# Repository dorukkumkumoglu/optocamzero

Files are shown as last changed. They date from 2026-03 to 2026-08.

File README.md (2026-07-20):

# Optocam Zero

Optocam Zero is a Raspberry Pi Zero based compact digital camera made using off the shelf components. 

I designed Optocam Zero to have a very compact, carry everywhere and have fun sort of camera. As I was inspired by Kodak charmera and similar toy cameras, I wanted it to be feel playful, enjoyable and be intuitive to use. I also aimed to make it relatively easy to build so that others can also build one and have fun with it. That's why all the case parts are easily printable and for the electronics it uses off the shelf components that are easy to find.

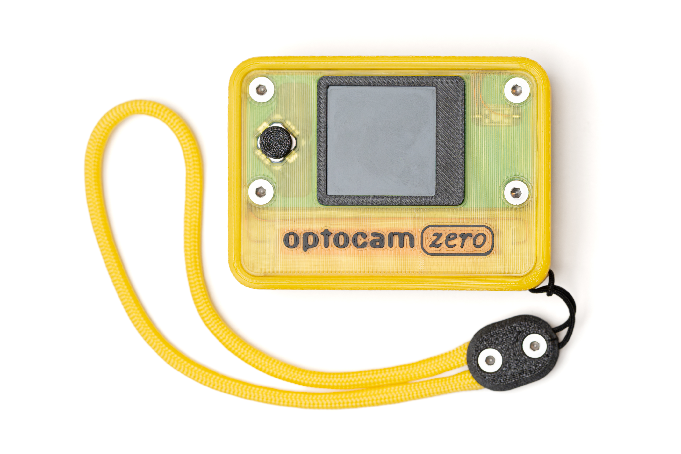
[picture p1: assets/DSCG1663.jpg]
exploded view


## Features
- **NEW** - GIF recording and playback.
- **NEW** - Custom filter maker (up to 5) in hotspot interface.
- Very compact and easy to carry in your pocket.
- Intuitive and simple camera interface and controls.
- Uses autofocus camera module.
- 8 photo filters included.
- Easy and fast image transfer through hotspot interface. Optimized both for mobile and desktop.
- Screen dimming when inactive to preserve battery.
- USB-C charging. Device can be used while charging.
- Interchangable battery.
- Off the shelf/ common components for the electronics.
- Fully 3D printed case parts (apart from fasteners).
- 3D printable TPU protective sleeve and lanyard design is available.

<br>

## Specs
- **UPDATE** - Now boots in 5 seconds with the buildroot image.
- **UPDATE** - Consistent 25-30 fps camera preview on the screen.
- 2592x2592px Jpeg image capture. Image saves in the background while preview stays active.
- 240x240px 1.4 inch lcd display.
- Uses 14500 type li-ion battery.
- 70–80 minutes of use per charge.
- Dimensions: 51×71×18mm (excluding camera and screen bump)
  
<br>

## Sample Photos

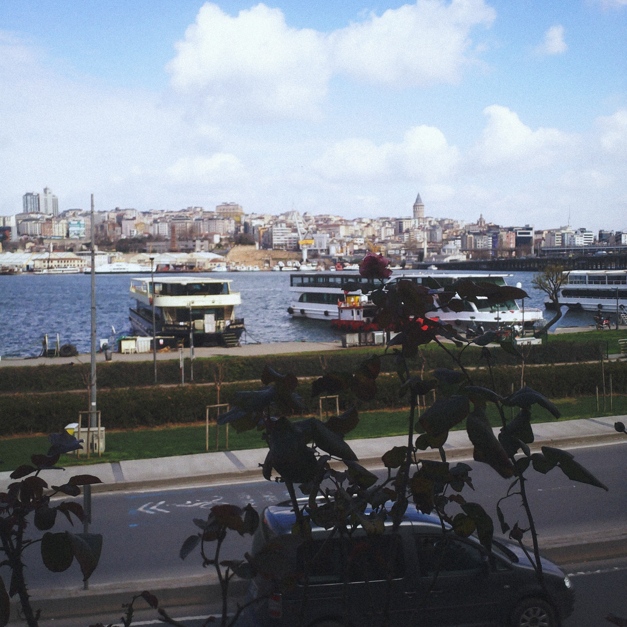
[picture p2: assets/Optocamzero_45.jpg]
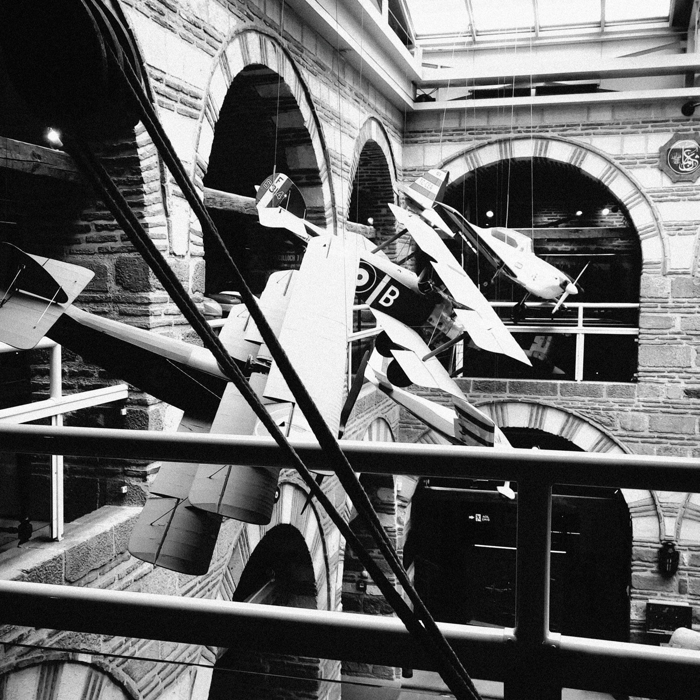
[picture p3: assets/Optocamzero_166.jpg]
 
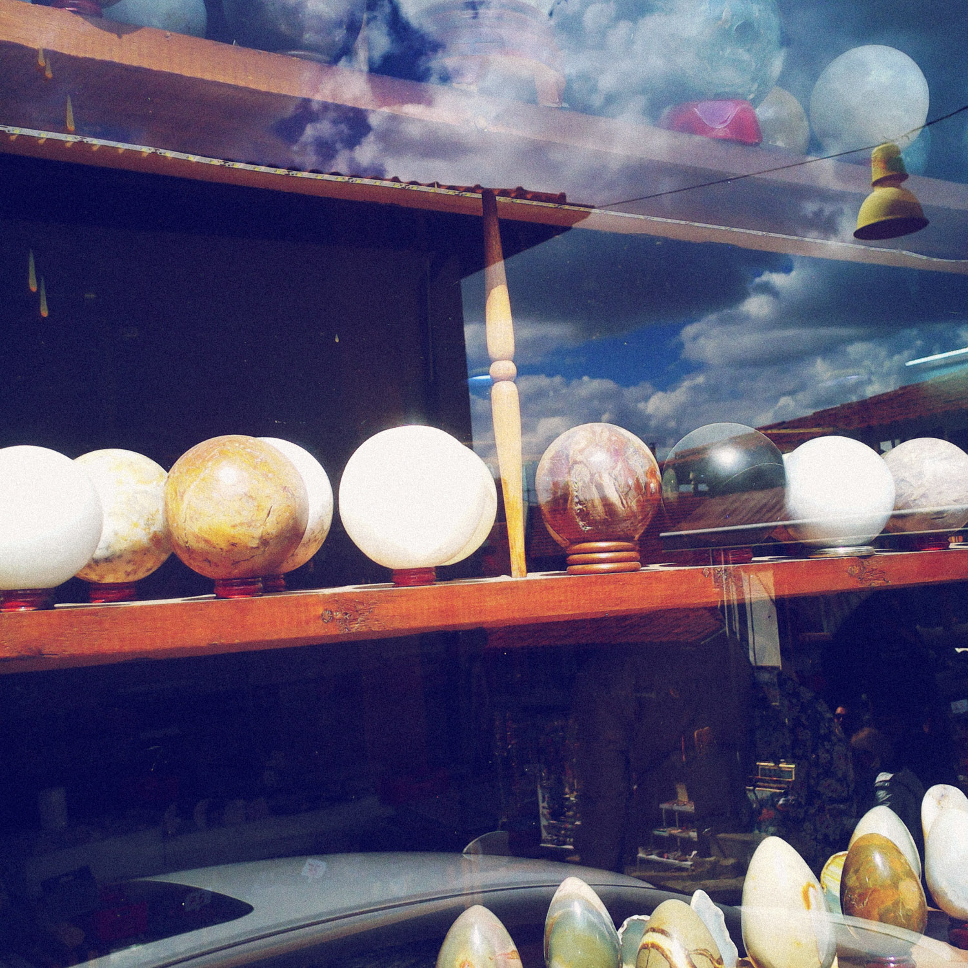
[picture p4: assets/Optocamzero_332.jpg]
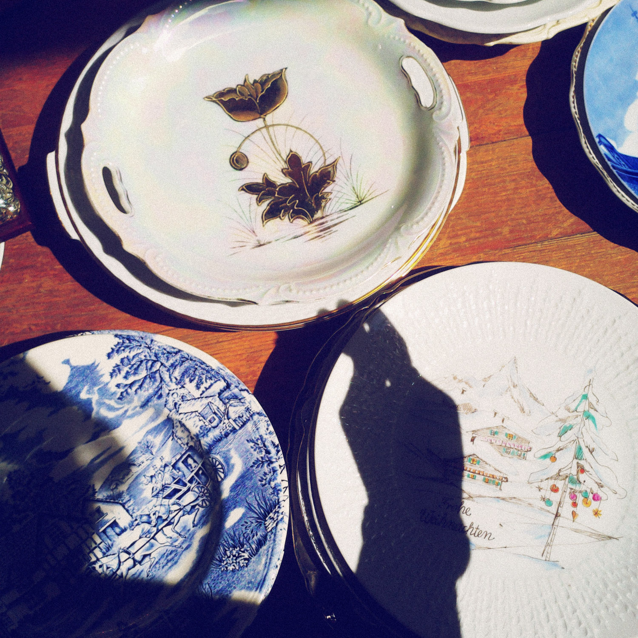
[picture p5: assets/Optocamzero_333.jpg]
 
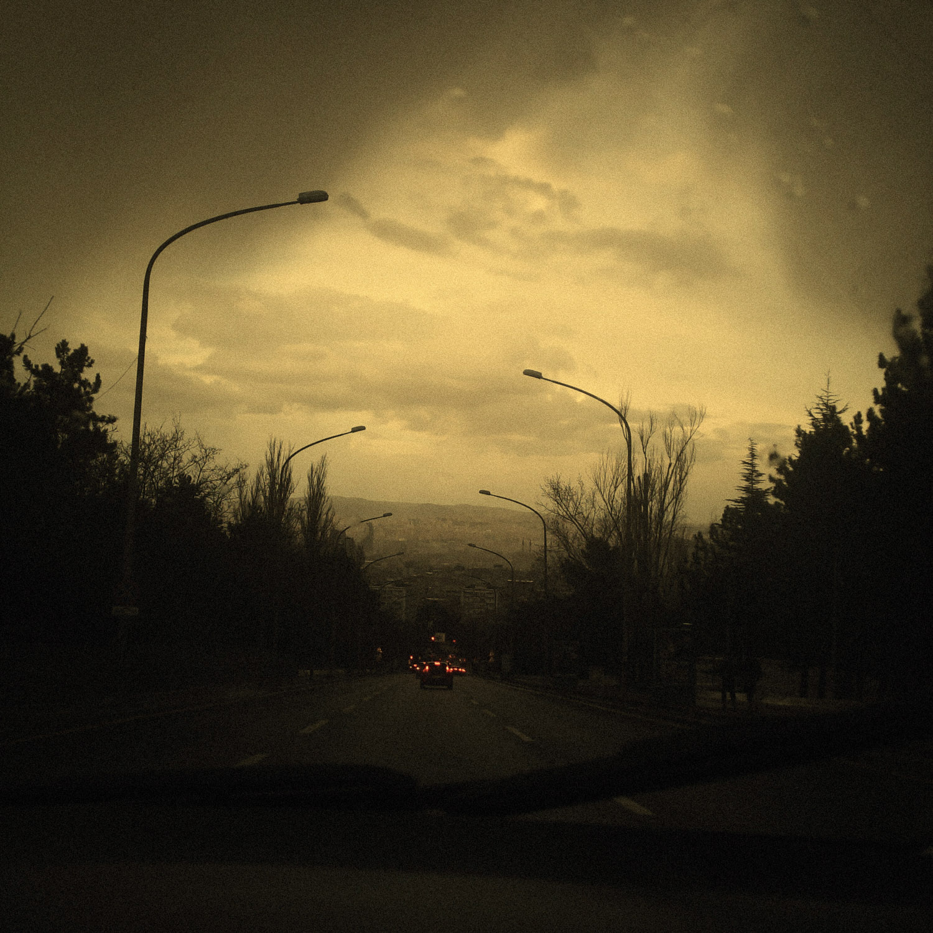
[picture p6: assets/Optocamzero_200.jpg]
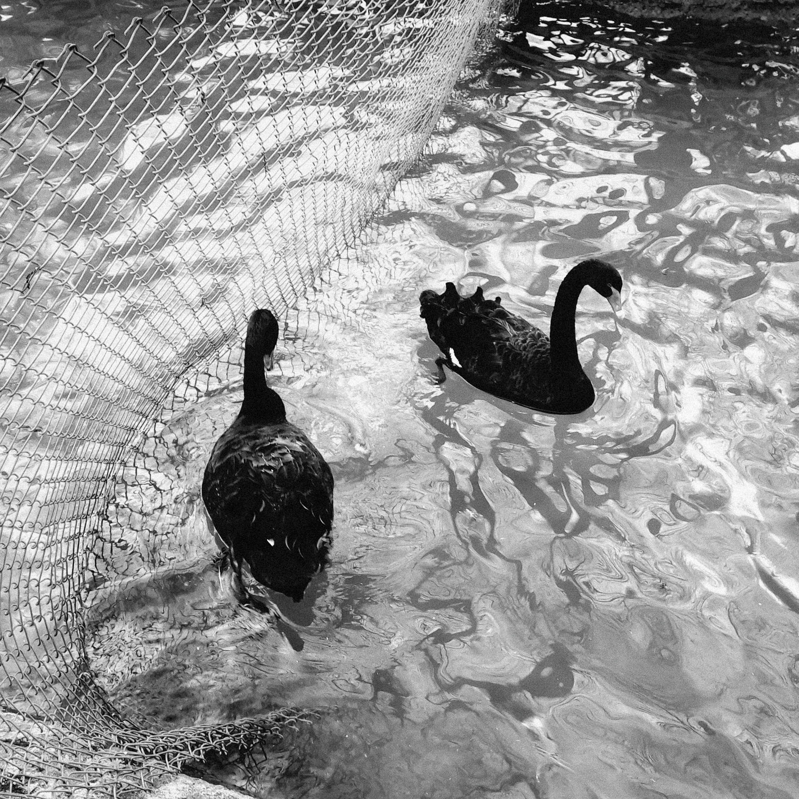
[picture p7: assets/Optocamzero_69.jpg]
 
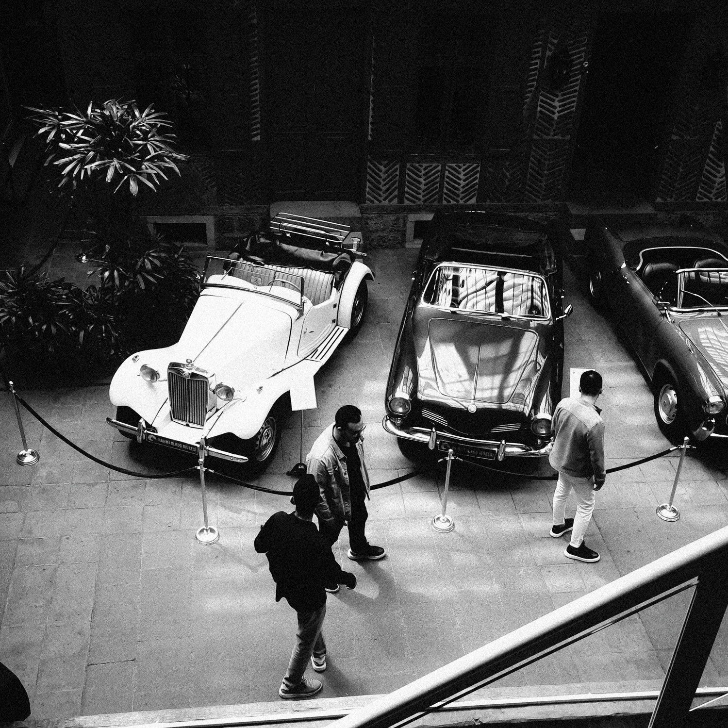
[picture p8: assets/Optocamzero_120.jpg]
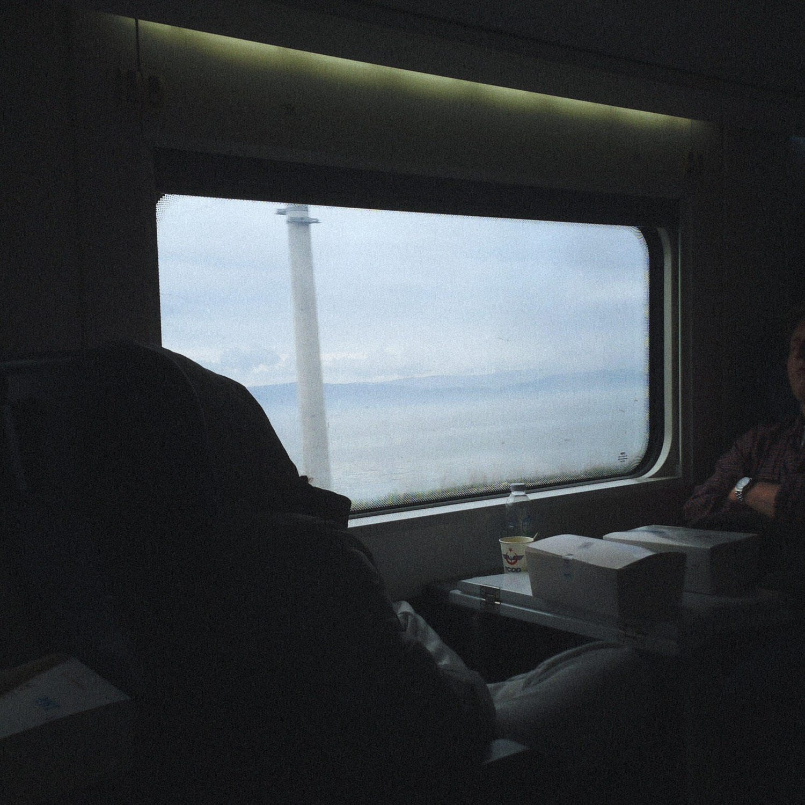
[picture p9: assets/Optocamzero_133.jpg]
 

<br>

## How to Build Optocam Zero?

Everything you need to build an Optocam Zero yourself is included in this repo.

All the 3d print files, Required parts list, and detailed step by step build guide can be found under the [hardware](hardware/) folder.

If you're considering building one, check the [BOM](hardware/BOM.md) to get an idea of the cost for required tools and parts.
Also, have a look at the [build guide](hardware/optocamzero-build-guide.pdf), it will give you a clear idea of what the build involves.

<br>

## Hardware

See the [hardware](hardware/) folder for:

- [Bill of materials](hardware/BOM.md).
- [Build guide](hardware/optocamzero-build-guide.pdf) (PDF).
- [Bambu Studio project files](hardware/print-ready/) ready to print for transparent PETG or PETG / PETG-CF.
- [Individual .stls](hardware/stls/) for camera parts.
- [CAD file](hardware/cad/optocamzero_V1.0.step) for customization.

<br>

## Software

See the [software](software/) folder for: 

- Optocam Zero code and installation guide.
- Camera controls information.

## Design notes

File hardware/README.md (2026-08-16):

# Optocam Zero Hardware

Everything you need to build an Optocam Zero, the 3D print files, required parts list, and detailed step by step build guide can be found in this hardware folder.

If you're considering building one, check the BOM to get an idea of the cost for required tools and parts. Also, have a look at the build guide, it will give you a clear idea of what the build involves.

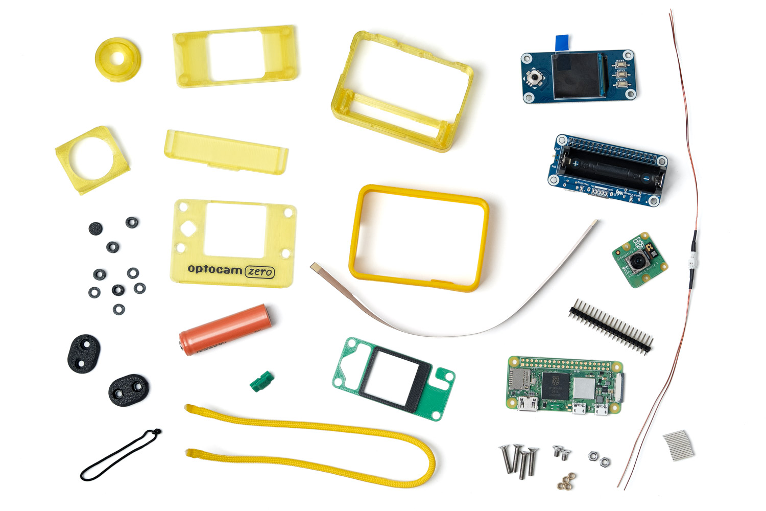
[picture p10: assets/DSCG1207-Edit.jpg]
exploded view


<br>

## 3D Printing the Parts

All parts are recommended to be printed with PETG for heat resistance. PLA parts may deform under heat generated by the electronics.

The parts are tested with PETG, transparent PETG and PETG-CF.

If you're using a Bambu Lab printer, ready to print Bambu Studio files are provided for Transparent PETG and PETG/PETG-CF. If you're printing transparent PETG, make sure the filament is well dried beforehand for maximum transparency.

All front and back pieces print flat on the plate, so whatever texture you have on your plate will be carried over to the front and back surfaces of your camera. For transparent PETG printing, I suggest using some kind of smooth plate if you want to achieve maximum transparency. Default textured plates will create a frosted look on transparent PETG, which has its own charm.

Two color 3D printing is only needed for the front cover logo and the two colored front spacer. If you don't want to have these, you can print all the pieces single color.

The optional case is printed with TPU. If you haven't printed with TPU before, check general TPU printing instructions.

**IMPORTANT:** The front spacer part that goes on top of the screen module has 2 versions with different thicknesses. This is because the LCD module on the display HAT may vary in thickness between batches. Test both front spacers and use the one that fits flush to the display HAT. Assembling the camera with the wrong front spacer part can damage the LCD.

<br>

## Before You Start

Make sure you have all the required parts, tools and 3D printed components ready before you begin.

Read through all the steps in the build guide before starting. Some steps have a specific order that can't be reversed easily.

This build requires basic soldering and desoldering. If you haven't soldered before, it's worth practicing on some scrap components first.

Take your time, especially with the ribbon cable (order extras to be safe) and the header pin soldering/desoldering. These are the most delicate parts of the build and mistakes here are difficult to undo. Be patient with it. 

<br>

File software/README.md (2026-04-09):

# Optocam Zero Software Installation and Interface Controls

<br>

## Requirements

- Completed Optocam Zero with the correct components.
- Micro sd card (16GB or larger, A2 type recommended for best performance).
- A computer with internet access.

<br>

## Installation

**1. Flash the SD card**

Download Raspberry Pi Imager from [raspberrypi.com/software](https://www.raspberrypi.com/software/) and install it. Select **Raspberry Pi Zero 2W** as the device and **Raspberry Pi OS Lite (32-bit) Bookworm** as the OS. You can find it under Raspberry Pi OS (other).

Before flashing, click **Edit Settings** and fill in your hostname, username, password, and WiFi credentials (remember to take note of this info). Go to the Services tab and enable SSH. Click Save, then flash the card.

**2. First boot**

Insert the SD card into the Pi and power it on. Wait about 1-2 minutes for it to boot and connect to your WiFi.

**3. Connect via SSH**

Open Terminal on your computer and run:

```
ssh your-username@your-hostname.local
```

Type `yes` when asked about the fingerprint, then enter your password.

**4. Run the installer**

```
sudo apt-get update
```

```
sudo apt-get install -y git
```

```
git clone https://github.com/dorukkumkumoglu/optocamzero.git && sudo bash optocamzero/software/install.sh
```

Installation takes about 10-15 minutes. The Pi reboots automatically when done and the camera starts immediately.

<br>

## Troubleshooting

**SSH shows "host key changed" error:**
```
ssh-keygen -R your-hostname.local
```

**Camera does not start after reboot:**
```
sudo systemctl status camera-auto.service
```

<br>

## Interface/ Controls

The device is turned on and off using the power switch on the right side. Reaching the camera preview after turning on the device takes 22 seconds.

Camera focus is set to continuous auto and cannot be adjusted manually. Camera shutter speed and ISO are set to auto and cannot be adjusted manually.

Currently, 8 different photo filters are included. You can switch between them. Color temperature can also be changed.

### Main camera preview screen controls
- Top left corner displays current color temperature (left-right joystick toggles between different color temperature modes).
- Top right corner displays current photo filter (up-down joystick toggles between different photo filters).
- Bottom left corner displays current ISO.
- Bottom right corner displays current shutter speed.
- A loading circle appears in the bottom center when an image is being saved. Wait for it to disappear before turning off the camera.

### Gallery controls
- Center joystick button opens the gallery.
- The numbers in the bottom left corner display the photo count and the currently displayed photo number.
- Left-right joystick navigates between photos in the gallery.
- Push joystick up for photo deletion. A confirmation overlay will appear. Push up once more to confirm deletion. Press any other button on the device to cancel.
- To exit the gallery, press the center joystick button or the shutter button. This will return to the main camera preview immediately.

### Transfer mode (Hotspot)
Optocam Zero includes a hotspot mode and photo transfer interface optimized for both mobile and desktop use.
- To activate transfer mode, long press the center joystick button.
- Long press the center joystick button again to exit transfer mode.
- To transfer images, connect your phone or computer to the Wi-Fi network called **Optocam Zero** (find the password on the screen) and open **192.168.4.1** in a browser.
- The dot in the top right corner and the number next to it indicate how many devices are currently connected to the hotspot. The dot turns green when a device is connected.

### Transfer interface (External Device)
After opening the address in a browser, the transfer interface will appear. All photos in your gallery are visible here and can be scrolled and browsed.

Below the header logo, the total image count and available free space are displayed.
- Photos can be downloaded individually by clicking the download icon in the top right corner of the photo.
- Multiple photos can be selected using the selectors in the top left corner of each image. After selection, you may batch download or delete the selected photos.
- For single image view, click on the image. Use the back button on screen to return, or swipe down on touch devices.
- In single image view, use the left-right arrow keys or swipe left-right to browse between photos.
- To view the full resolution image, click the HQ button in single image view.

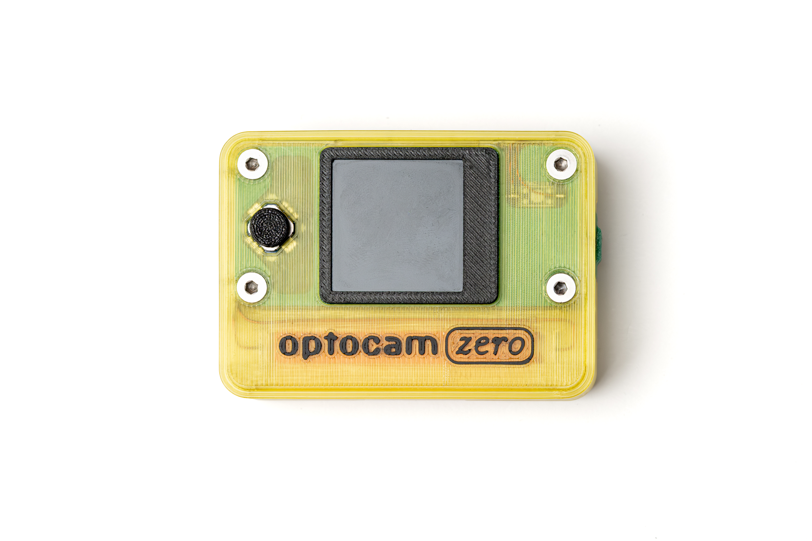
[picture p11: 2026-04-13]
assets/DSCG1642.jpg

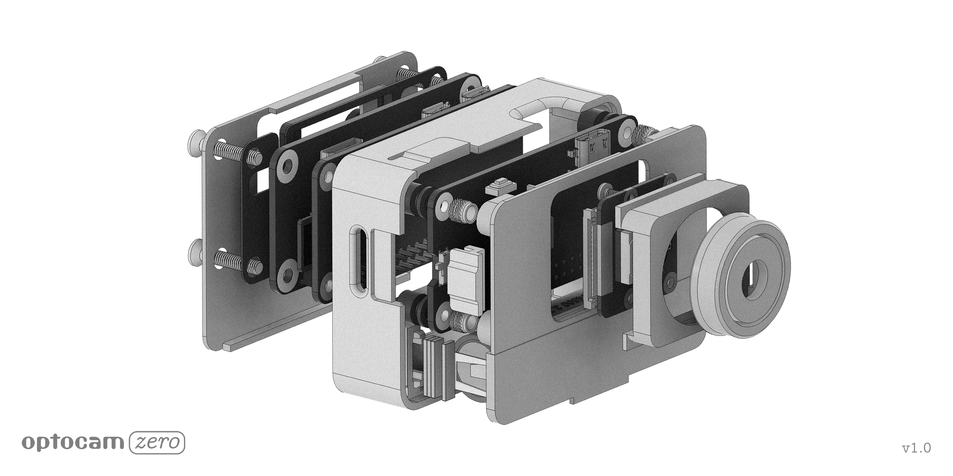
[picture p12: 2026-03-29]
assets/exploded-2.png

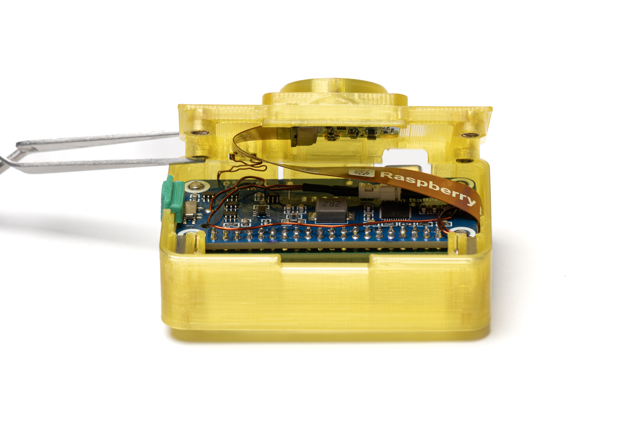
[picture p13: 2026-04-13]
assets/DSCG1636.jpg

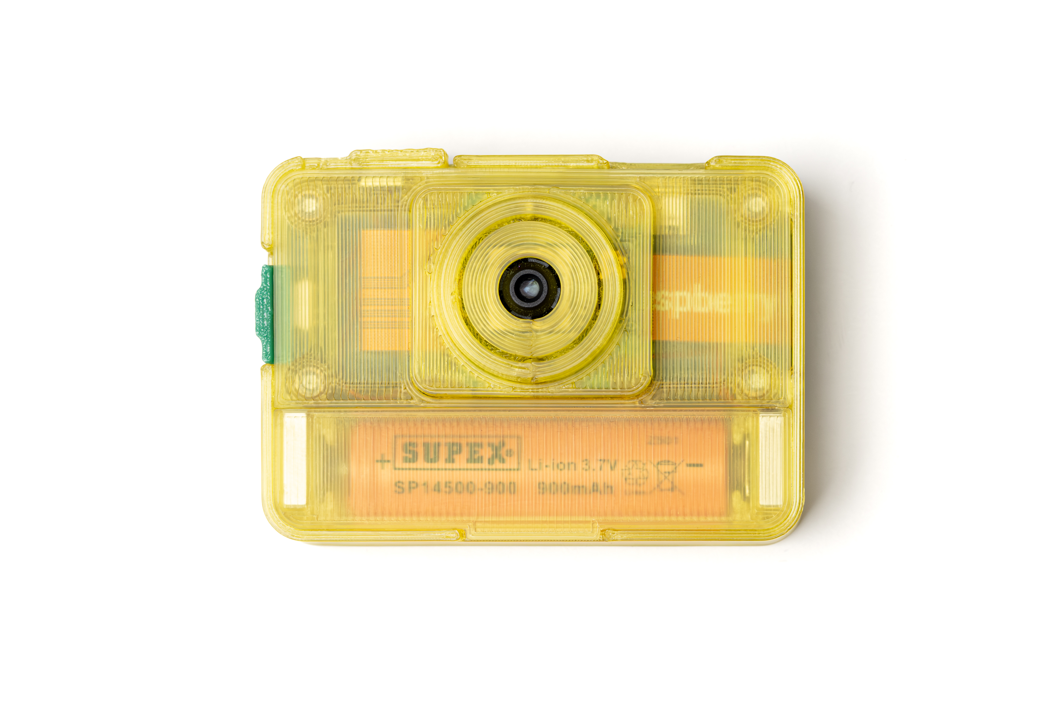
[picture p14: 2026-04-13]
assets/DSCG1643.jpg

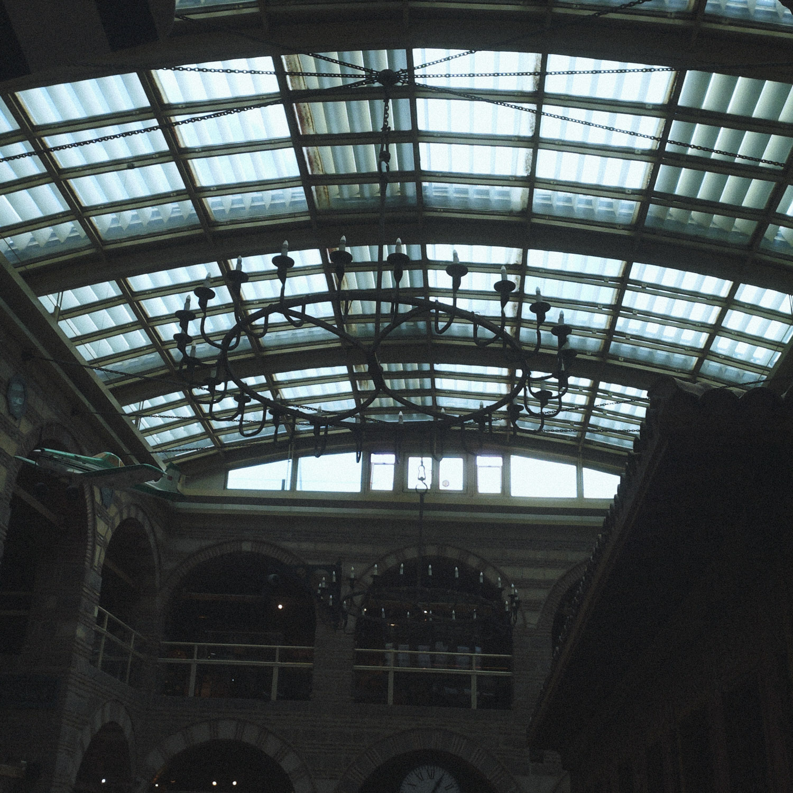
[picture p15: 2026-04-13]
assets/Optocamzero_97-2.jpg

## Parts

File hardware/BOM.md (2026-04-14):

# Optocam Zero V1.0 Bill of Materials
Doruk Kumkumoğlu 2026

<br>

## Electronics

| Item | Qty |
|---|-----|
| [Raspberry Pi Zero 2 W (without header)](https://thepihut.com/products/raspberry-pi-zero-2) | x1 |
| [Raspberry Pi Camera Module 3](https://thepihut.com/products/raspberry-pi-camera-module-3) | x1 |
| Micro SD Card A2 Class — Raspberry Pi or other high quality brands, minimum 16GB | x1 |
| [Waveshare Li-ion Battery HAT for Raspberry Pi](https://www.waveshare.com/li-ion-battery-hat.htm) | x1 |
| [Waveshare 1.3" IPS 240x240 LCD Display HAT for Raspberry Pi](https://www.waveshare.com/1.3inch-lcd-hat.htm) | x1 |
| [Camera Adapter Cable – Raspberry Pi Zero compatible (200mm)](https://thepihut.com/products/camera-adapter-cable-for-raspberry-pi-5) | x1 |
| 14500 Type 3.7V 900 mAh Li-ion Battery | x1 |
| Micro JST 1.25 Pitch 2 Pin Male and Female Connector Set (With 24 AWG Cable) — or 24 AWG cable (≥50cm length) | x1 |
| [2×20 Double Row Male GPIO Header](https://thepihut.com/products/break-away-0-1-2x20-pin-strip-dual-male-header) | x1 |
| 0.3mm Ø Enameled Copper Wire (≥30cm length) — or any thin signal cable | x1 |

<br>

## Fasteners

| Item | Qty |
|---|-----|
| M3×16mm Stainless Steel Hex-Drive Flat Head Screw | x4 |
| M2×6mm Screw (comes with the Waveshare Display HAT) | x2 | 
| [M3×4mm×4mm Brass Heat Set Insert](https://www.adafruit.com/product/4255) | x4 |
| 12×3×1mm Neodymium Magnet | x8 |

<br>

## Optional Fasteners

| Item | Qty |
|---|-----|
| M3×6mm Stainless Steel Hex-Drive Flat Head Screw (For Lanyard Lock) | x2 |
| M3 Stainless Steel Nut (For Lanyard Lock) | x2 |

<br>

## 3D Printed Parts and Materials

| Item | Material | Qty |
|---|---|-----|
| Enclosure | PETG | x1 |
| Back Panel | PETG | x1 |
| Camera Cover | PETG | x1 |
| Camera Circle | PETG | x1 |
| Front Spacer | PETG | x1 |
| Front Panel | PETG | x1 |
| Battery Door | PETG | x1 |
| Battery Level Visor | PETG | x1 |
| On/Off Button | PETG | x1 |
| Joystick Button | PETG | x1 |
| Washer 1mm | PETG | x4 |
| Washer 4mm | PETG | x4 |

<br>

## Optional 3D Printed Parts

| Item | Material | Qty |
|---|---|-----|
| Lanyard Lock Parts | PETG | x1 |
| Camera Sleeve | TPU | x1 |

<br>

## Optional – Cords & Straps

| Item | Qty |
|---|-----|
| Paracord – 1mm Ø, ≥30cm length | x1 |
| Paracord – 4mm Ø, ≥1m length | x1 |

<br>

## Tools

- 3D Printer
- Soldering Iron
- M3 Heat Set Insert Tip For Soldering Iron
- Solder Pump
- Solder
- Flux
- Kapton Tape
- 2mm (M3) Hex Driver
- Utility Knife
- Pliers
- Side Cutter
- Tweezers

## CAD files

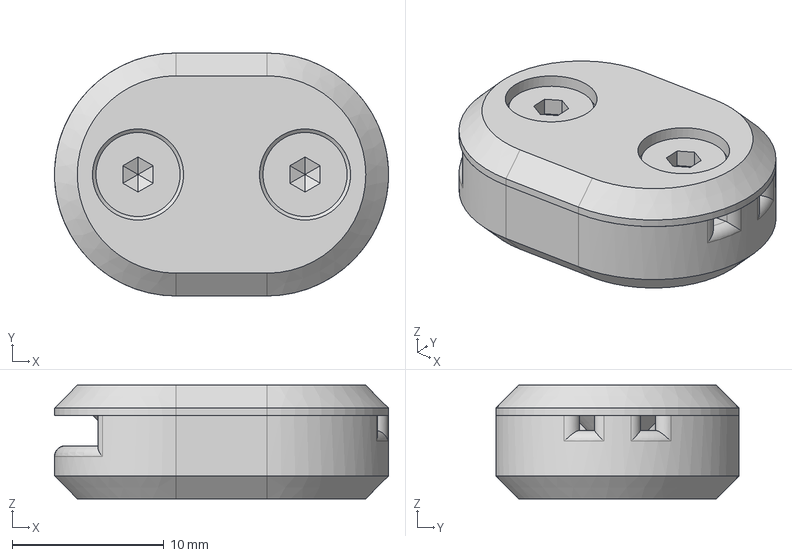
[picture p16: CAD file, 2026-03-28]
hardware/cad/lanyard-lock_V1.0.step
22.0 x 16.0 x 7.50 mm
ISO 10642 - M3 x 6 Steel 8.8 Plain
ISO 10642 - M3 x 6 Steel 8.8 Plain_1
ISO 4035 - M3 Steel 6 Plain
ISO 4035 - M3 Steel 6 Plain_1
Top
Bottom

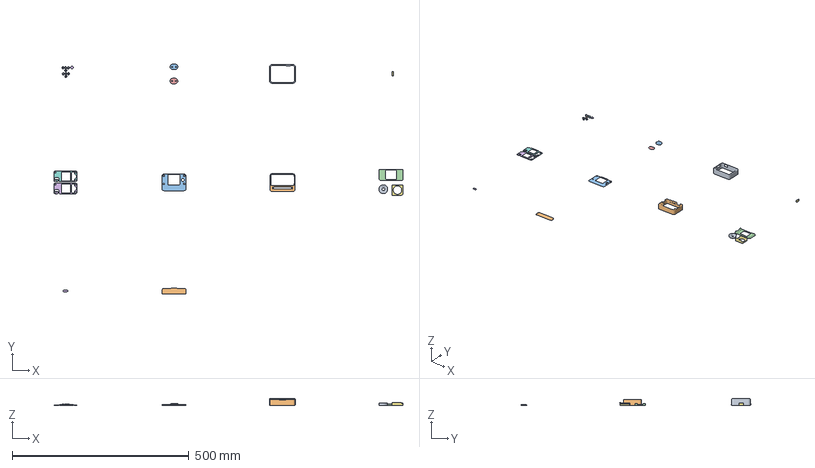
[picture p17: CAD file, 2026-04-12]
hardware/print-ready/optocamzero_v1.0_bambustudio.3mf
988.1 x 650.9 x 19.5 mm
Case
enclosure-opaque_v1.0.stl
top
Back Cover
bottom
front-spacer_v1.0.stl
Camera Cover
Front spacer B (For thicker screen)
Camera Circle
Battery Door
Front Panel
washer 4mm x 4
washer 1mm x 4
Joystick Button
On/ Off Button
Battery level visor

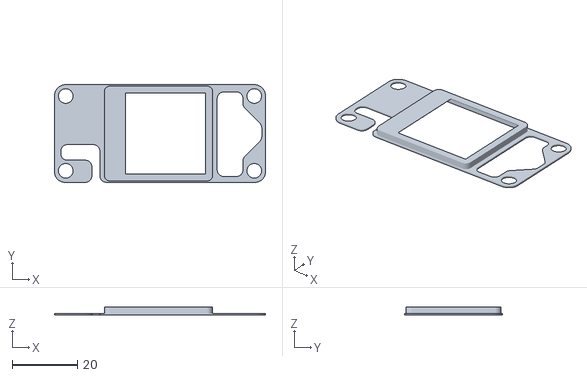
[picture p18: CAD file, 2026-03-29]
hardware/stls/front-spacer_v1.0.stl
64.9 x 30.0 x 2.40

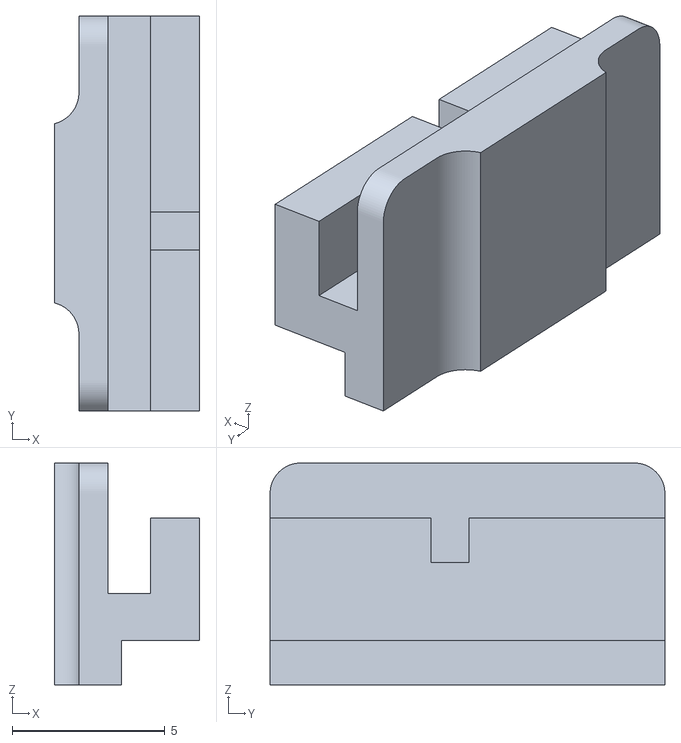
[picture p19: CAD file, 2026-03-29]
hardware/stls/on-off-button_v1.0.stl
4.75 x 12.9 x 7.27

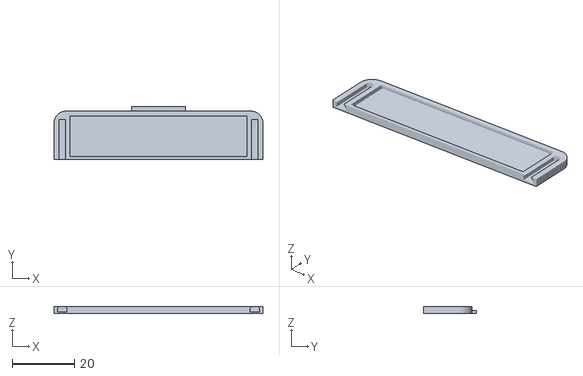
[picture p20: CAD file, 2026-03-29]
hardware/stls/battery-door_v1.0.stl
67.3 x 17.0 x 2.20

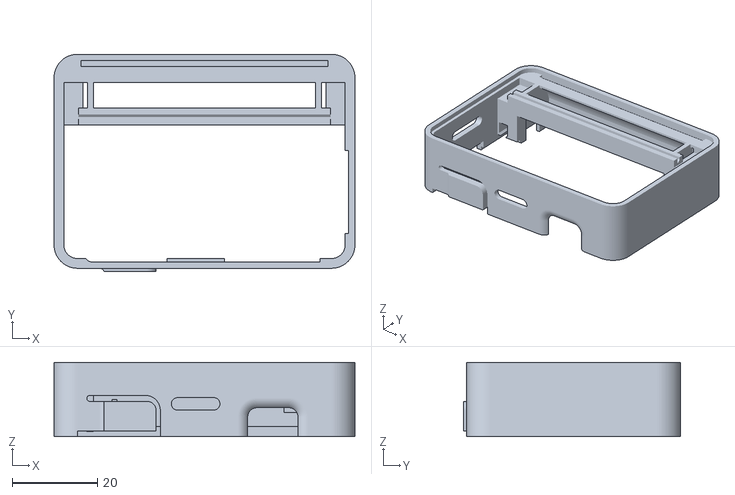
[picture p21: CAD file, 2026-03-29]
hardware/stls/enclosure-opaque_v1.0.stl
70.5 x 50.9 x 17.4

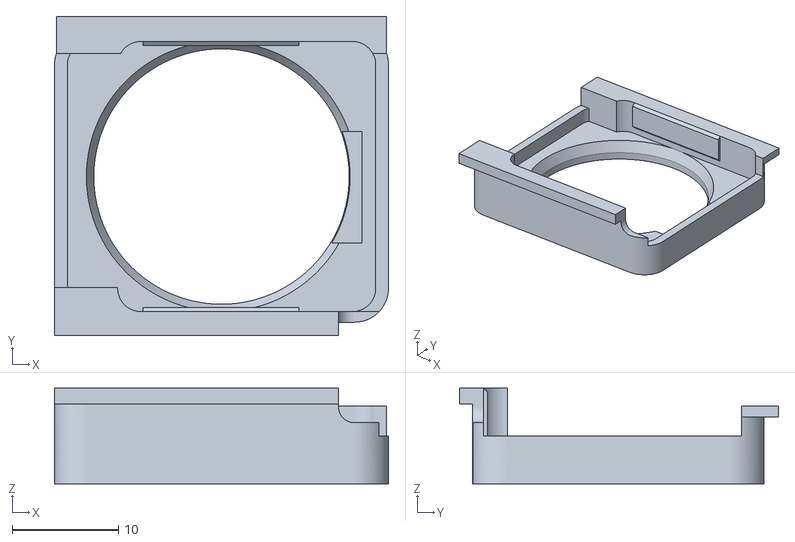
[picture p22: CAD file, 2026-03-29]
hardware/stls/camera-cover_v1.0.stl
31.4 x 30.0 x 9.00

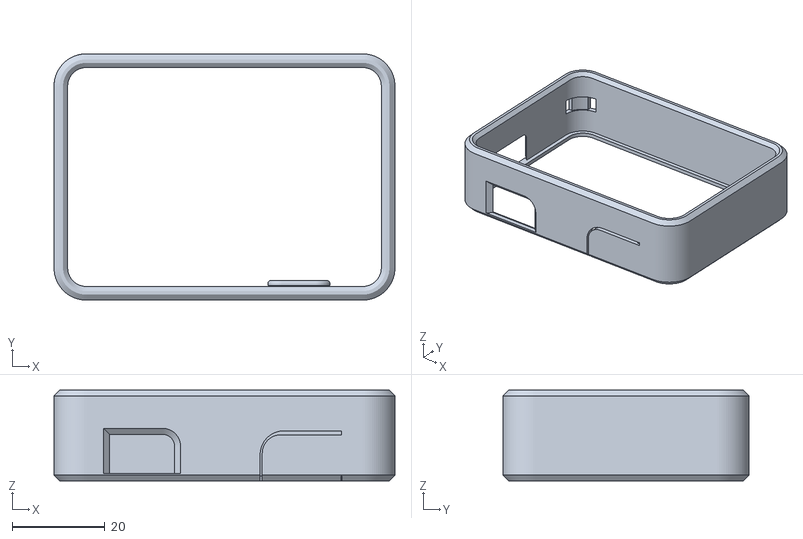
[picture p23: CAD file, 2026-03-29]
hardware/stls/case_v1.0.stl
73.4 x 53.0 x 19.5

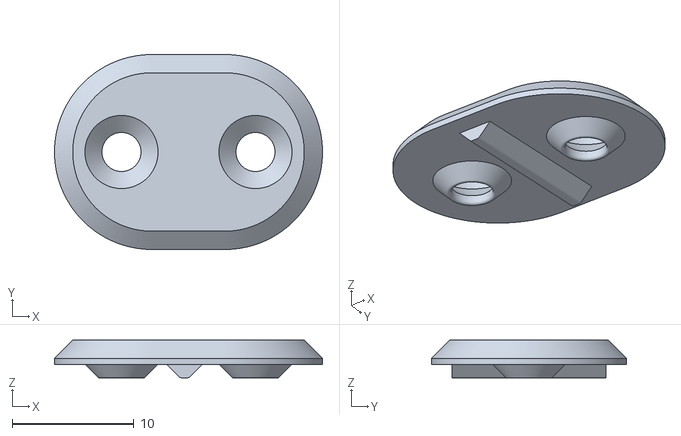
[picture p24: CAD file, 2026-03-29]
hardware/stls/lanyard-lock-top_v1.0.stl
22.0 x 16.0 x 3.12

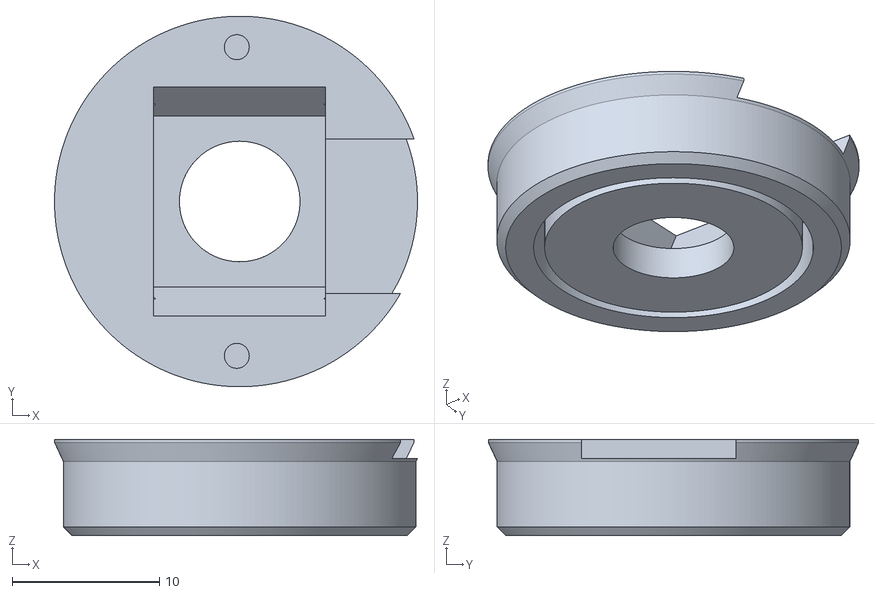
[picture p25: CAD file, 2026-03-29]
hardware/stls/camera-circle_v1.0.stl
24.7 x 25.2 x 6.55

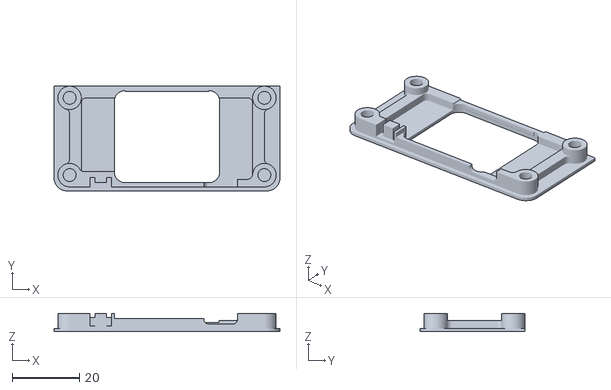
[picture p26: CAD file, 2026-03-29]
hardware/stls/back-panel_v1.0.stl
67.3 x 31.2 x 5.50

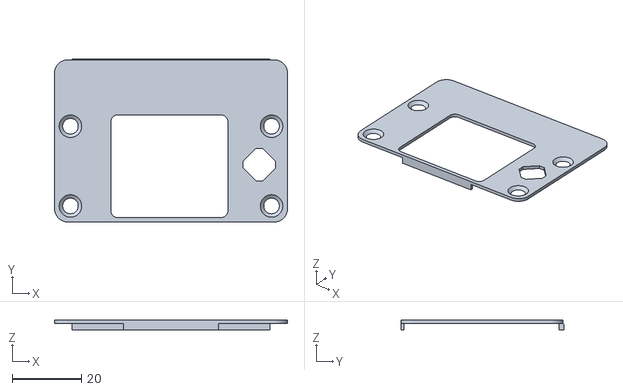
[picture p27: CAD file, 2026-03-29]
hardware/stls/front-panel_v1.0.stl
67.2 x 47.1 x 3.00

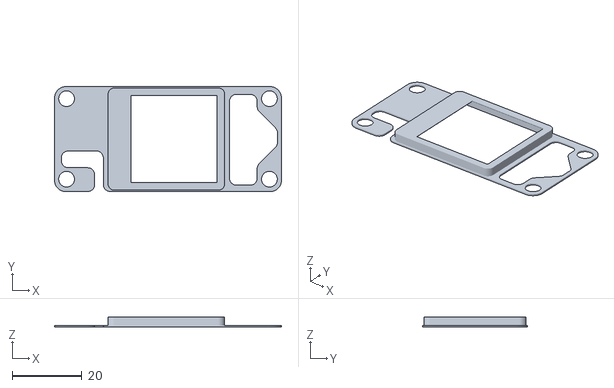
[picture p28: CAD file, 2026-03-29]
hardware/stls/front-spacer-thicker-screen_v1.0.stl
64.9 x 30.0 x 2.90

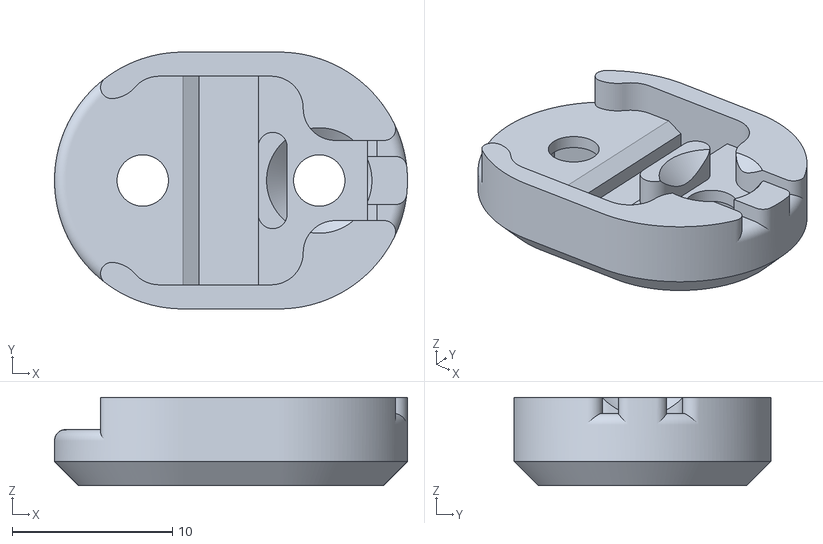
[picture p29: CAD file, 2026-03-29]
hardware/stls/lanyard-lock-bottom_v1.0.stl
22.0 x 16.0 x 5.50

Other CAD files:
hardware/print-ready/optocamzero-transparent_v1.0_bambustudio.3mf
hardware/stls/enclosure_v1.0.stl
hardware/stls/joystick-button_v1.0.stl
hardware/stls/battery-level-visor_v1.0.stl

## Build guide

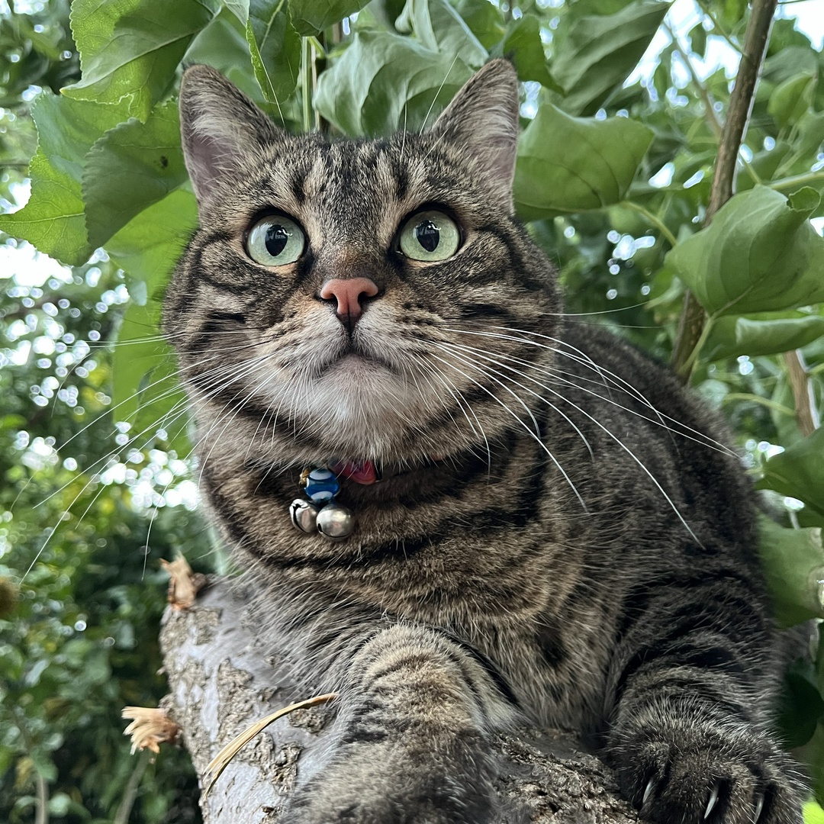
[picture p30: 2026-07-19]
software/firmware-buildroot/overlay/usr/share/optocam/calib_photo.jpg

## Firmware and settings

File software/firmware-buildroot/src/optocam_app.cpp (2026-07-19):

/* optocam_app.cpp — OptoCam Buildroot Stage-2 app, step 1.
 * Everything optocam_preview.cpp does (5s boot preview), plus:
 *   - buttons via gpiochip ioctls (capture GPIO21, preview GPIO20,
 *     joystick L5/R26/PRESS13/U6/D19 — all pull-up, active-low)
 *   - shutter: switch to 2592x2592 still, JPEG q92 (libjpeg-turbo),
 *     rotated 90° to match the display, saved to /data/photos/
 *     Optocamzero_N.jpg with fsync (power-cut costs at most this file)
 *   - white shutter-flash on the display for feedback
 * Boot-critical path is unchanged: display first, cache-warm, entity wait.
 */
#include <cstdio>
#include <cstdlib>
#include <cstdint>
#include <cstring>
#include <unistd.h>
#include <fcntl.h>
#include <dirent.h>
#include <sys/ioctl.h>
#include <sys/mman.h>
#include <sys/mount.h>
#include <sys/stat.h>
#include <map>
#include <vector>
#include <memory>
#include <atomic>
#include <mutex>
#include <chrono>
#include <condition_variable>
#include <thread>
#include <linux/spi/spidev.h>
#include <linux/gpio.h>
#include <linux/media.h>
#include <libcamera/libcamera.h>
#include <jpeglib.h>
#include <setjmp.h>
#include <csignal>
#include "optocam_hud.h"
#include "optocam_gif.h"

using namespace libcamera;

/* ---------- ST7789 display (validated in Stage-1) ---------- */
static bool g_madctl_legacy = false;        /* A/B: original 0x70 panel mode */
static int spifd, rst_fd, dc_fd, bl_fd;
static int gpio_out(int chipfd, unsigned off, int val) {
    struct gpiohandle_request r; memset(&r, 0, sizeof r);
    r.lineoffsets[0] = off; r.lines = 1; r.flags = GPIOHANDLE_REQUEST_OUTPUT;
    r.default_values[0] = val; strcpy(r.consumer_label, "optocam");
    if (ioctl(chipfd, GPIO_GET_LINEHANDLE_IOCTL, &r) < 0) { perror("linehandle"); return -1; }
    return r.fd;
}
static void gpio_set(int fd, int v) { struct gpiohandle_data d; d.values[0] = v; ioctl(fd, GPIOHANDLE_SET_LINE_VALUES_IOCTL, &d); }
/* Memory-mapped fast path for the backlight pin (BCM 24): at the dim duty the
 * PWM pulse is 63µs, and the gpiochip ioctl's kernel-crossing latency under
 * IRQ load lands on the pulse edges as faint brightness wander. A register
 * store makes the edges nanosecond-exact regardless of load. The line stays
 * requested as output via gpiochip; both paths reach the same pad. */
static volatile uint32_t *g_gpioreg = nullptr;
static void bl_fast_init(void) {
    int fd = open("/dev/gpiomem", O_RDWR | O_SYNC);
    if (fd < 0) return;                     /* no gpiomem: ioctl fallback */
    void *m = mmap(nullptr, 4096, PROT_READ | PROT_WRITE, MAP_SHARED, fd, 0);
    close(fd);
    if (m != MAP_FAILED) g_gpioreg = (volatile uint32_t *)m;
}
static inline void bl_set(int v) {
    if (g_gpioreg) g_gpioreg[v ? 7 : 10] = 1u << 24;   /* GPSET0 / GPCLR0 */
    else gpio_set(bl_fd, v);
}
static void spi_write(const uint8_t *b, size_t len) {
    size_t off = 0;
    while (off < len) { size_t n = len - off; if (n > 65536) n = 65536;
        ssize_t w = write(spifd, b + off, n); if (w <= 0) { perror("spi"); return; } off += (size_t)w; }
}
static void dcmd(uint8_t c) { gpio_set(dc_fd, 0); spi_write(&c, 1); }
static void ddata(const uint8_t *d, size_t n) { gpio_set(dc_fd, 1); spi_write(d, n); }

static void display_init(bool soft) {
    /* soft: the early-splash binary already initialised the panel and is
     * holding the GPIO lines — kill it, re-grab the lines WITHOUT resetting
     * the panel (its RAM keeps showing the splash), and just take over. */
    if (soft) { system("killall optocam_splash 2>/dev/null"); usleep(50000); }
    /* at boot we race spi-bcm2835's async probe — retry until the nodes exist
     * (the "backlight on, nothing else" boot failure) */
    int chip = -1;
    for (int t = 0; t < 500 && (chip = open("/dev/gpiochip0", O_RDONLY)) < 0; t++) usleep(20000);
    rst_fd = gpio_out(chip, 27, 1); dc_fd = gpio_out(chip, 25, 0);
    bl_fd = gpio_out(chip, 24, soft ? 1 : 0);          /* keep backlight lit on takeover */
    close(chip);
    spifd = -1;
    for (int t = 0; t < 500 && (spifd = open("/dev/spidev0.0", O_RDWR)) < 0; t++) usleep(20000);
    if (spifd < 0) printf("optocam: SPIDEV OPEN FAILED\n");
    uint8_t mode = SPI_MODE_0, bits = 8; uint32_t sp = 100000000;
    ioctl(spifd, SPI_IOC_WR_MODE, &mode); ioctl(spifd, SPI_IOC_WR_BITS_PER_WORD, &bits);
    ioctl(spifd, SPI_IOC_WR_MAX_SPEED_HZ, &sp);
    uint8_t mode2 = SPI_MODE_0, bits2 = 8; uint32_t sp2 = 100000000;
    ioctl(spifd, SPI_IOC_WR_MODE, &mode2); ioctl(spifd, SPI_IOC_WR_BITS_PER_WORD, &bits2);
    ioctl(spifd, SPI_IOC_WR_MAX_SPEED_HZ, &sp2);
    if (soft) return;                                  /* panel already showing splash */
    gpio_set(rst_fd, 1); usleep(50000); gpio_set(rst_fd, 0); usleep(50000); gpio_set(rst_fd, 1); usleep(80000);
    struct { uint8_t c, n, d[16]; } in[] = {
        {(uint8_t)0x36,(uint8_t)1,{g_madctl_legacy ? (uint8_t)0x70 : (uint8_t)0x00}},{0x3A,1,{0x05}},{0xB2,5,{0x0C,0x0C,0x00,0x33,0x33}},{0xB7,1,{0x35}},{0xBB,1,{0x35}},
        {0xC0,1,{0x2C}},{0xC2,1,{0x01}},{0xC3,1,{0x13}},{0xC4,1,{0x20}},{0xC6,1,{0x0F}},{0xD0,2,{0xA4,0xA1}},
        {0xE0,14,{0xF0,0x00,0x04,0x04,0x04,0x05,0x29,0x33,0x3E,0x38,0x12,0x12,0x28,0x30}},
        {0xE1,14,{0xF0,0x07,0x0A,0x0D,0x0B,0x07,0x28,0x33,0x3E,0x36,0x14,0x14,0x29,0x32}},
        {0x21,0,{0}},{0x11,0,{0}},
    };
    for (unsigned i = 0; i < sizeof(in)/sizeof(in[0]); i++) { dcmd(in[i].c); if (in[i].n) ddata(in[i].d, in[i].n); if (in[i].c == 0x11) usleep(80000); }
    dcmd(0x29);   /* backlight stays OFF until the splash is drawn (like the app) */
}
static uint8_t fb565[240*240*2];
static unsigned FW, FH, FSTRIDE;
/* fused contrast + RGB565 LUTs, exactly the Python app's display path:
 * (x - 128) * 1.15 + 123, then masked/shifted per channel */
static uint16_t R565[256], G565[256], B565[256];
/* optional saturation stage: 4th dispcal float ≠ 1.0 activates a 3x3 colour
 * matrix (white-point gains folded in) baked into 9 int16 LUTs — per pixel:
 * 9 loads + 6 adds + clamps. sat==1.0 keeps the original 3-LUT path. */
static int16_t M9[3][3][256];
static bool g_sat_on = false;
static inline uint16_t px565(uint8_t r, uint8_t g, uint8_t b) {
    if (!g_sat_on) return R565[r] | G565[g] | B565[b];
    int rv = M9[0][0][r] + M9[0][1][g] + M9[0][2][b];
    int gv = M9[1][0][r] + M9[1][1][g] + M9[1][2][b];
    int bv = M9[2][0][r] + M9[2][1][g] + M9[2][2][b];
    rv = rv < 0 ? 0 : rv > 255 ? 255 : rv;
    gv = gv < 0 ? 0 : gv > 255 ? 255 : gv;
    bv = bv < 0 ? 0 : bv > 255 ? 255 : bv;
    return (uint16_t)((rv & 0xF8) << 8) | (uint16_t)((gv & 0xFC) << 3) | (uint16_t)((bv & 0xF8) >> 3);
}
/* camera WB shift — the amber/blue fine-tune real cameras offer: a fixed RGB
 * trim applied to CAMERA pixels only (live preview, photos, gifs), never the
 * UI. Predictable and AWB-independent, unlike tuning-file knobs where the WB
 * gains and the CT-dependent colour matrix partially cancel each other.
 * /data/.wbtrim (or baked /usr/share/optocam/wbtrim): "R G B" floats. */
static uint8_t WBL[3][256];
static bool g_wb_on = false;
static void build_wb_trim(void) {
    float tr = 1, tg = 1, tb = 1;
    FILE *f = fopen("/data/.wbtrim", "r");
    if (!f) f = fopen("/usr/share/optocam/wbtrim", "r");
    if (f) {
        float r, g, b;
        if (fscanf(f, "%f %f %f", &r, &g, &b) == 3 &&
            r > 0.5f && r <= 1.5f && g > 0.5f && g <= 1.5f && b > 0.5f && b <= 1.5f) {
            tr = r; tg = g; tb = b;
        }
        fclose(f);
    }
    for (int i = 0; i < 256; i++) {
        auto q = [](float v) { return (uint8_t)(v < 0 ? 0 : v > 255 ? 255 : v); };
        WBL[0][i] = q(i * tr); WBL[1][i] = q(i * tg); WBL[2][i] = q(i * tb);
    }
    g_wb_on = tr != 1.0f || tg != 1.0f || tb != 1.0f;
}
static void wb_apply(uint8_t *p, size_t npx, bool bgr) {
    if (!g_wb_on) return;
    int ri = bgr ? 2 : 0, bi = bgr ? 0 : 2;
    for (size_t i = 0; i < npx; i++, p += 3) {
        p[ri] = WBL[0][p[ri]]; p[1] = WBL[1][p[1]]; p[bi] = WBL[2][p[bi]];
    }
}
/* device baseline contrast: photos map i -> (i-128)*1.15 + 123. The calibration
 * "contrast" slider scales that 1.15 (default keeps the shipped look). */
static constexpr float BASE_CONTRAST = 1.15f;
/* Calibration transfer applied per display pixel, baked into the LUTs so it
 * costs nothing per frame. Order: contrast -> gamma -> per-channel gain (+ an
 * optional saturation matrix). Returns a normalised 0..1 tone; the per-channel
 * gain is applied by the caller. */
static inline float calib_tone(int i, float contrast, float inv_gamma) {
    float c = (i - 128) * contrast + 123.0f;
    c = c < 0 ? 0 : c > 255 ? 255 : c;
    float n = c / 255.0f;
    if (inv_gamma < 0.999f || inv_gamma > 1.001f) n = powf(n, inv_gamma);
    return n;
}
/* core LUT builder: per-channel white-point gains, saturation, gamma and
 * contrast. Split out so the transfer-mode screen calibrator can rebuild the
 * LUTs live from slider values (see /data/.calib) without re-reading a file. */
static void build_565_luts_from(float gr, float gg, float gb, float sat,
                                float gamma, float contrast) {
    float inv_g = (gamma > 0.05f) ? 1.0f / gamma : 1.0f;
    auto q = [](float v) -> uint16_t { return v < 0 ? 0 : v > 255 ? 255 : (uint16_t)v; };
    for (int i = 0; i < 256; i++) {
        float n = calib_tone(i, contrast, inv_g);
        R565[i] = (q(255.0f * n * gr) & 0xF8) << 8;
        G565[i] = (q(255.0f * n * gg) & 0xFC) << 3;
        B565[i] = (q(255.0f * n * gb) & 0xF8) >> 3;
    }
    if (sat < 0.99f || sat > 1.01f) {
        /* standard luma-preserving saturation matrix, white gains folded in */
        const float W[3] = {gr, gg, gb}, LR = 0.299f, LG = 0.587f, LB = 0.114f;
        const float S[3][3] = {
            {LR + (1-LR)*sat, LG*(1-sat),      LB*(1-sat)},
            {LR*(1-sat),      LG + (1-LG)*sat, LB*(1-sat)},
            {LR*(1-sat),      LG*(1-sat),      LB + (1-LB)*sat}};
        for (int i = 0; i < 3; i++)
            for (int j = 0; j < 3; j++)
                for (int v = 0; v < 256; v++) {
                    float base = 255.0f * calib_tone(v, contrast, inv_g);
                    M9[i][j][v] = (int16_t)lrintf(W[i] * S[i][j] * base);
                }
        g_sat_on = true;
    } else g_sat_on = false;
}
/* Calibrated backlight duty, 51..255 (255 = solid DC, no PWM). The "screen
 * brightness" calibration slider lands here — real luminance via the BL pin,
 * never a pixel gain, so it can't clip highlights or cost tonal bits. */
static std::atomic<int> g_bl_level(255);
/* panel white-point calibration: this unit's LCD batch runs bluer than the
 * original device's (identical init registers + identical conversion were
 * verified — the difference is the glass). /data/.dispcal holds up to seven
 * floats "GR GG GB [SAT GAMMA CONTRAST BACKLIGHT]" (written by the hotspot
 * Screen-Calibration panel on save); absent fields fall back to neutral / the
 * baked contrast / full backlight. The baked fallback file stays 3-float and
 * back-compatible. Gain bounds are INCLUSIVE of 0.2 — the server clamps to
 * exactly 0.2, and `>` here used to reject such a profile wholesale. */
static bool read_dispcal(const char *path, float &gr, float &gg, float &gb,
                         float &sat, float &gamma, float &contrast, float &bl) {
    FILE *cal = fopen(path, "r");
    if (!cal) return false;
    float r, g, b, s = 1.0f, ga = 1.0f, ct = BASE_CONTRAST, lv = 1.0f;
    int n = fscanf(cal, "%f %f %f %f %f %f %f", &r, &g, &b, &s, &ga, &ct, &lv);
    fclose(cal);
    if (n >= 3 && r >= 0.2f && r <= 2.5f && g >= 0.2f && g <= 2.5f && b >= 0.2f && b <= 2.5f) {
        gr = r; gg = g; gb = b;
        sat      = (n >= 4 && s  >= 0.0f && s  <= 2.5f) ? s  : 1.0f;
        gamma    = (n >= 5 && ga >= 0.3f && ga <= 3.0f) ? ga : 1.0f;
        contrast = (n >= 6 && ct >= 0.2f && ct <= 2.5f) ? ct : BASE_CONTRAST;
        bl       = (n >= 7 && lv >= 0.2f && lv <= 1.0f) ? lv : 1.0f;
        return true;
    }
    return false;
}
static void build_565_luts(void) {
    float gr = 1.0f, gg = 1.0f, gb = 1.0f, sat = 1.0f, gamma = 1.0f, contrast = BASE_CONTRAST, bl = 1.0f;
    if (!read_dispcal("/data/.dispcal", gr, gg, gb, sat, gamma, contrast, bl))   /* /data mounts late — */
        read_dispcal("/usr/share/optocam/dispcal", gr, gg, gb, sat, gamma, contrast, bl);  /* baked fallback */
    build_565_luts_from(gr, gg, gb, sat, gamma, contrast);
    g_bl_level.store((int)lrintf(bl * 255.0f));
}
/* Writes now happen in the panel's PHYSICAL scan order (MADCTL 0x00) and the
 * old hardware remap (0x70: MV|MX) is applied in software — same image, but
 * the write pointer moves WITH the scan instead of across it, which turns the
 * harsh diagonal tearing into occasional mild banding (esp-idf #15265 clue).
 * Variant selectable via /tmp/rot (0-7) for on-device axis calibration. */
static int fb_variant(void) { return g_madctl_legacy ? 1 : 2; }
static inline void fb_map(int variant, int i, int j, int &x, int &y) {
    switch (variant & 7) {
    case 0: x = 239 - i; y = j; break;        /* P70 guess: MV + MX */
    case 1: x = i;       y = j; break;
    case 2: x = i;       y = 239 - j; break;
    case 3: x = 239 - i; y = 239 - j; break;
    case 4: x = j;       y = i; break;
    case 5: x = 239 - j; y = i; break;
    case 6: x = j;       y = 239 - i; break;
    default: x = 239 - j; y = 239 - i; break;
    }
}
static void fb_store_565(const uint8_t *vis565) {       /* splash path (RGB565 in) */
    int v = fb_variant();
    for (int i = 0; i < 240; i++)
        for (int j = 0; j < 240; j++) {
            int x, y; fb_map(v, i, j, x, y);
            fb565[(i*240 + j)*2]     = vis565[(y*240 + x)*2];
            fb565[(i*240 + j)*2 + 1] = vis565[(y*240 + x)*2 + 1];
        }
}
static void fb_flush(void) {
    uint8_t win[4] = {0x00,0x00,0x00,0xEF};
    dcmd(0x2A); ddata(win, 4); dcmd(0x2B); ddata(win, 4); dcmd(0x2C); ddata(fb565, sizeof fb565);
}
static void display_blit(const uint8_t *rgb) {
    unsigned ox = FW > 240 ? (FW - 240) / 2 : 0, oy = FH > 240 ? (FH - 240) / 2 : 0;
    int v = fb_variant();
    for (int i = 0; i < 240; i++) {
        uint8_t *out = fb565 + i * 240 * 2;
        for (int j = 0; j < 240; j++) {
            int x, y; fb_map(v, i, j, x, y);
            int sx = 239 - y, sy = x;                 /* 90° to match panel mount */
            const uint8_t *px = rgb + (size_t)(oy + sy) * FSTRIDE + (size_t)(ox + sx) * 3;
            uint16_t c = px565(px[2], px[1], px[0]);
            out[j*2] = c >> 8; out[j*2+1] = c & 0xFF;
        }
    }
    fb_flush();
}
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
int main() {
    install_crash_handlers();
    logstep("main enter");
    g_madctl_legacy = access("/tmp/madctl-legacy", F_OK) == 0;
    build_565_luts();
    build_wb_trim();
    filters_init();
    if (!g_te.init("/usr/share/optocam/cmunvt.ttf")) printf("optocam: FONT INIT FAILED\n");
    logstep("luts+font ready");
    /* early-splash takeover: if S01 claimed the panel, wait for it (≤3s) and
     * take over WITHOUT reinitialising — splash stays perfectly still until
     * the first preview frame replaces it */
    bool soft = false;
    if (access("/tmp/splash-claimed", F_OK) == 0) {
        for (int t = 0; t < 150 && access("/tmp/display-up", F_OK) != 0; t++) usleep(20000);
        soft = access("/tmp/display-up", F_OK) == 0;
    }
    display_init(soft);
    if (!soft) {
        /* splash.raw (RGB565 blob) if present, else black */
        static uint8_t vis[240*240*2];
        FILE *sf = fopen("/usr/share/optocam/splash.raw", "rb");
        if (sf) { size_t rd = fread(vis, 1, sizeof vis, sf); (void)rd; fclose(sf); }
        else memset(vis, 0, sizeof vis);
        fb_store_565(vis);
        fb_flush();
        gpio_set(bl_fd, 1);      /* splash drawn -> light it: no white flash */
    }
    buttons_init();
    logstep("display up, starting camera");

    /* (page-cache warm moved to S01: it must start BEFORE our exec to overlap
     * the library loading, not after) */
    printf("optocam: waiting for imx708 sensor link...\n"); fflush(stdout);
    for (int t = 0; t < 600; t++) {                /* 20ms polls, up to 12s */
        /* S02's backgrounded modprobes can race/fail; retry them ourselves
         * rather than waiting on a sensor that will never appear */
        if (t == 200 || t == 400)
            system("modprobe i2c-bcm2835; modprobe bcm2835-unicam; "
                   "modprobe bcm2835-isp; modprobe imx708; modprobe dw9807-vcm");
        int found = 0;
        for (int m = 0; m < 8 && !found; m++) {
            char path[32]; snprintf(path, sizeof path, "/dev/media%d", m);
            int fd = open(path, O_RDONLY);
            if (fd < 0) continue;
            struct media_entity_desc e; memset(&e, 0, sizeof e);
            while (1) {
                e.id |= MEDIA_ENT_ID_FLAG_NEXT;
                if (ioctl(fd, MEDIA_IOC_ENUM_ENTITIES, &e) < 0) break;
                if (strstr(e.name, "imx708")) { found = 1; break; }
            }
            close(fd);
        }
        if (found) { printf("optocam: imx708 linked at ~%d ms\n", t * 20); fflush(stdout); break; }
        usleep(20000);
    }

    setenv("LIBCAMERA_LOG_LEVELS", "*:ERROR", 1);
    signal(SIGALRM, wd_timeout);
    wd_arm(25);            /* covers cm.start/acquire; setup_stream re-arms */
    logstep("cm.start begin");
    CameraManager cm; cm.start();
    logstep("cm.start done");
    for (int i = 0; i < 50 && cm.cameras().empty(); i++) usleep(100000);
    if (cm.cameras().empty()) { printf("optocam: NO CAMERAS\n"); return 1; }
    camera = cm.cameras()[0];
    camera->acquire();

    std::unique_ptr<CameraConfiguration> previewCfg =
        camera->generateConfiguration({ StreamRole::Viewfinder });
    previewCfg->at(0).size = Size(240, 240);
    previewCfg->at(0).pixelFormat = formats::RGB888;
    previewCfg->at(0).bufferCount = 4;

    std::unique_ptr<CameraConfiguration> stillCfg =
        camera->generateConfiguration({ StreamRole::StillCapture });
    stillCfg->at(0).size = Size(2592, 2592);
    stillCfg->at(0).pixelFormat = formats::RGB888;
    stillCfg->at(0).bufferCount = 1;

    std::unique_ptr<CameraConfiguration> gifCfg =
        camera->generateConfiguration({ StreamRole::Viewfinder });
    gifCfg->at(0).size = Size(640, 640);
    gifCfg->at(0).pixelFormat = formats::RGB888;
    gifCfg->at(0).bufferCount = 4;

    std::thread([] {
        /* warm the filter sprites with a PRIVATE TextEngine: each build is
         * ~200ms of supersampled blur+lanczos, and doing that under
         * g_render_mtx visibly stuttered the fresh preview. Off-mutex the
         * builds run on another core; only the finished-sprite insert takes
         * the lock (microseconds). 2s delay keeps even the memory-bandwidth
         * cost out of the boot attention window. */
        usleep(2000000);
        saving_spinner_sprite(0);
        TextEngine te;
        if (!te.init("/usr/share/optocam/cmunvt.ttf")) return;
        /* presets only: /data may not be mounted yet, so customs (>= CUSTOM_BASE)
         * are built lazily by filter_indicator() when first shown */
        for (int i = 0; i < CUSTOM_BASE; i++) {
            Img s = build_filter_indicator(FILTERS[i], te);
            std::lock_guard<std::mutex> rk(g_render_mtx);
            if (!g_filt_ind_cache.count(i)) g_filt_ind_cache.emplace(i, std::move(s));
        }
        for (int i = 0; i < 2; i++) {
            Img s = build_gif_mode_indicator(i, te);
            std::lock_guard<std::mutex> rk(g_render_mtx);
            if (!g_gif_ind_built[i]) {
                g_gif_ind_cache[i] = std::move(s);
                g_gif_ind_built[i] = true;
            }
        }
        {
            std::lock_guard<std::mutex> rk(g_render_mtx);
            centre_msg_sprite("GIF Mode");
            centre_msg_sprite("Photo Mode");
        }
        printf("optocam: sprites warmed\n"); fflush(stdout);
    }).detach();

    camera->requestCompleted.connect(requestComplete);
    if (!setup_stream(previewCfg.get(), true)) return 1;
    printf("optocam: preview running\n"); fflush(stdout);

    /* pre-warm the first-capture path: mounting /data (journal replay after a
     * power-cut can take >1s) and the cold photo-dir scan otherwise happen
     * synchronously inside the first shutter press — the "first capture
     * freezes longer" bug */
    std::thread([] {
        for (int i = 0; access("/tmp/optocam-data-ready", F_OK) != 0 && i < 30; i++)
            usleep(100000);
        data_ready();
        build_565_luts();          /* /data/.dispcal wasn't readable at start */
        build_wb_trim();           /* same for /data/.wbtrim */
        build_custom_filters();    /* /data/.effect0-4 — the custom filters */
        load_startup_defaults();   /* /data/.defaults — startup filter + WB */
        load_ae_limits();          /* /data/.aelimits — min shutter / max ISO */
        warm_initial_gallery_cache();
    }).detach();

    /* ---------- main loop: exact port of button_handler + mode loop ---------- */
    enum { M_PREVIEW, M_GALLERY, M_SPLASH, M_OFF, M_TRANSFER };
    int mode = M_PREVIEW;
    bool camera_running = true;
    int gal_idx = 0; bool gal_confirm = false, gal_dirty = false;
    bool gif_mode = false;
    double gif_label_time = 0, empty_msg_time = 0, nospace_msg_time = 0;
    bl_fast_init();
    std::thread(backlight_pwm_thread).detach();
    double idle_last = now_s(); bool idle_dimmed = false;
    uint8_t prev = 0;
    double last_capture = 0, last_preview_btn = 0, last_joy_ud = 0, last_lr = 0;
    bool cap_was_down = false, cap_long_fired = false; double cap_down_time = 0;
    bool joy_was_down = false, joy_long_fired = false; double joy_down_time = 0;
    double transfer_last_refresh = 0, transfer_last_activity = 0;
    std::vector<double> joy_press_times;
    double left_held = 0, right_held = 0, last_scroll = 0;
    const double DEB = 0.3, CAP_LONG = 0.6, HOLD_TH = 0.35, FAST_IV = 0.10;
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

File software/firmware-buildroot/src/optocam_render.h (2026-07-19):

/* optocam_render.h — PIL-equivalent rendering core for the exact OptoCam port.
 * RGBA straight-alpha images, FreeType text (PIL's own engine, same cmunvt.ttf),
 * Gaussian blur (3-pass box approximation), alpha_composite, BILINEAR/LANCZOS
 * resize, and the PIL ImageDraw shapes the HUD uses. Header-only.
 */
#pragma once
#include <cstdint>
#include <cstring>
#include <cstdio>
#include <cmath>
#include <vector>
#include <string>
#include <map>
#include <algorithm>
#include <ft2build.h>
#include FT_FREETYPE_H

struct Img {                       /* RGBA8, straight alpha */
    int w = 0, h = 0;
    std::vector<uint8_t> px;       /* w*h*4 */
    Img() {}
    Img(int W, int H) : w(W), h(H), px((size_t)W * H * 4, 0) {}
    uint8_t *at(int x, int y) { return &px[((size_t)y * w + x) * 4]; }
    const uint8_t *at(int x, int y) const { return &px[((size_t)y * w + x) * 4]; }
};

/* ---------- alpha compositing (PIL Image.alpha_composite) ---------- */
inline void alpha_composite(Img &dst, const Img &src) {
    size_t n = (size_t)dst.w * dst.h;
    for (size_t i = 0; i < n; i++) {
        uint8_t *d = &dst.px[i * 4];
        const uint8_t *s = &src.px[i * 4];
        unsigned sa = s[3];
        if (sa == 0) continue;
        if (sa == 255) { d[0]=s[0]; d[1]=s[1]; d[2]=s[2]; d[3]=255; continue; }
        unsigned da = d[3];
        unsigned oa = sa + da * (255 - sa) / 255;
        if (oa == 0) { d[0]=d[1]=d[2]=d[3]=0; continue; }
        for (int c = 0; c < 3; c++)
            d[c] = (uint8_t)((s[c] * sa + d[c] * da * (255 - sa) / 255) / oa);
        d[3] = (uint8_t)oa;
    }
}
inline void scale_alpha(Img &img, float a) {           /* PIL putalpha(point(p*a)) */
    size_t n = (size_t)img.w * img.h;
    for (size_t i = 0; i < n; i++)
        img.px[i * 4 + 3] = (uint8_t)std::min(255, (int)(img.px[i * 4 + 3] * a));
}

/* ---------- Gaussian blur (PIL ImageFilter.GaussianBlur equivalent) ----------
 * Three box blurs approximate a Gaussian; radii per Ivan Kutskir's method. */
inline void _box_blur_ch(std::vector<float> &src, std::vector<float> &dst, int w, int h, int r) {
    /* horizontal then vertical accumulation, radius r box */
    float iarr = 1.0f / (r + r + 1);
    for (int y = 0; y < h; y++) {                       /* horizontal */
        float *s = &src[(size_t)y * w], *d = &dst[(size_t)y * w];
        float acc = s[0] * (r + 1);
        for (int x = 0; x < r && x < w; x++) acc += s[std::min(x, w - 1)];
        for (int x = 0; x < w; x++) {
            acc += s[std::min(x + r, w - 1)] - s[std::max(x - r - 1, 0)];
            d[x] = acc * iarr;
        }
    }
    for (int x = 0; x < w; x++) {                       /* vertical, dst in place via temp col */
        float acc = dst[x] * (r + 1);
        for (int y = 0; y < r && y < h; y++) acc += dst[(size_t)std::min(y, h - 1) * w + x];
        std::vector<float> col(h);
        for (int y = 0; y < h; y++) {
            acc += dst[(size_t)std::min(y + r, h - 1) * w + x] - dst[(size_t)std::max(y - r - 1, 0) * w + x];
            col[y] = acc * iarr;
        }
        for (int y = 0; y < h; y++) dst[(size_t)y * w + x] = col[y];
    }
    src = dst;
}
inline void gaussian_blur(Img &img, float radius) {
    if (radius <= 0) return;
    /* box sizes for 3 passes */
    float sigma = radius;                               /* PIL: radius == sigma */
    int n = 3;
    float wIdeal = std::sqrt(12.0f * sigma * sigma / n + 1.0f);
    int wl = (int)wIdeal; if (wl % 2 == 0) wl--;
    int wu = wl + 2;
    float mIdeal = (12.0f * sigma * sigma - n * wl * wl - 4.0f * n * wl - 3.0f * n) / (-4.0f * wl - 4.0f);
    int m = (int)std::round(mIdeal);
    int w = img.w, h = img.h;
    /* blur premultiplied so transparent black pixels don't darken edges */
    std::vector<float> ch[4], tmp((size_t)w * h);
    for (int c = 0; c < 4; c++) ch[c].resize((size_t)w * h);
    size_t np = (size_t)w * h;
    for (size_t i = 0; i < np; i++) {
        float a = img.px[i * 4 + 3] / 255.0f;
        ch[0][i] = img.px[i * 4 + 0] * a;
        ch[1][i] = img.px[i * 4 + 1] * a;
        ch[2][i] = img.px[i * 4 + 2] * a;
        ch[3][i] = img.px[i * 4 + 3];
    }
    for (int c = 0; c < 4; c++)
        for (int p = 0; p < 3; p++) {
            int r = (p < m ? wl : wu) / 2;
            if (r > 0) _box_blur_ch(ch[c], tmp, w, h, r);
        }
    for (size_t i = 0; i < np; i++) {
        float a = ch[3][i];
        img.px[i * 4 + 3] = (uint8_t)std::clamp(a, 0.0f, 255.0f);
        float ia = a > 0.5f ? 255.0f / a : 0.0f;
        img.px[i * 4 + 0] = (uint8_t)std::clamp(ch[0][i] * ia, 0.0f, 255.0f);
        img.px[i * 4 + 1] = (uint8_t)std::clamp(ch[1][i] * ia, 0.0f, 255.0f);
        img.px[i * 4 + 2] = (uint8_t)std::clamp(ch[2][i] * ia, 0.0f, 255.0f);
    }
}

/* ---------- resize: BILINEAR + LANCZOS(3), premultiplied like PIL ---------- */
inline Img resize_bilinear(const Img &src, int W, int H) {
    Img out(W, H);
    for (int y = 0; y < H; y++) {
        float fy = (y + 0.5f) * src.h / H - 0.5f;
        int y0 = (int)std::floor(fy); float ty = fy - y0;
        int y1 = std::min(y0 + 1, src.h - 1); y0 = std::max(y0, 0);
        for (int x = 0; x < W; x++) {
            float fx = (x + 0.5f) * src.w / W - 0.5f;
            int x0 = (int)std::floor(fx); float tx = fx - x0;
            int x1 = std::min(x0 + 1, src.w - 1); x0 = std::max(x0, 0);
            const uint8_t *p00 = src.at(x0, y0), *p10 = src.at(x1, y0),
                          *p01 = src.at(x0, y1), *p11 = src.at(x1, y1);
            float a00=p00[3], a10=p10[3], a01=p01[3], a11=p11[3];
            float oa = (a00*(1-tx)+a10*tx)*(1-ty) + (a01*(1-tx)+a11*tx)*ty;
            uint8_t *o = out.at(x, y);
            for (int c = 0; c < 3; c++) {
                float v = (p00[c]*a00*(1-tx)+p10[c]*a10*tx)*(1-ty)
                        + (p01[c]*a01*(1-tx)+p11[c]*a11*tx)*ty;
                o[c] = oa > 0.5f ? (uint8_t)std::clamp(v / oa, 0.0f, 255.0f) : 0;
            }
            o[3] = (uint8_t)std::clamp(oa, 0.0f, 255.0f);
        }
    }
    return out;
}
inline float _lanczos(float x) {
    if (x == 0) return 1.0f;
    if (x <= -3.0f || x >= 3.0f) return 0.0f;
    float px = (float)M_PI * x;
    return 3.0f * std::sin(px) * std::sin(px / 3.0f) / (px * px);
}
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

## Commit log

2026-03-27 Switch to CC BY-SA 4.0 license
2026-03-27 Fix boot time: add i2c disable and st7789 overlay
2026-03-27 Add consoleblank=0 and fsck.mode=skip to cmdline.txt setup
    Prevents console blanking from dimming the display before the camera
    script starts, and skips initramfs fsck to avoid ~5.8s boot delay on
    fresh Pi OS installs.
2026-03-27 Reset idle dim timer when viewfinder starts
    Ensures the 90-second idle dim countdown begins when the camera
    viewfinder first becomes active, not during initialization.
    [optocamzero.py]
2026-03-28 Add initial hardware CAD files for Optocam Zero V1.0
2026-03-28 Add lanyard lock V1.0 CAD file
    [lanyard lock_V1.0.step]
2026-03-28 Move CAD files into hardware/cad/
    [lanyard lock_V1.0.step]
2026-03-28 Add Bill of Materials
2026-03-28 Remove horizontal dividers from BOM
2026-03-28 Add spacing between sections in BOM
2026-03-28 Remove em dash from BOM title
2026-03-28 Move BOM into hardware folder
2026-03-29 Rename Back Cover to Back Panel in BOM
2026-03-29 Add STL files for Optocam Zero V1.0
    [back-panel_v1.0.stl, battery-door_v1.0.stl, battery-level-visor_v1.0.stl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]
2026-03-29 Rename CAD files to kebab-case and add print-ready folder
    [lanyard-lock_V1.0.step, optocamzero-transparent_v1.0_bambustudio.3mf, optocamzero_v1.0_bambustudio.3mf]
2026-04-12 Update CAD and print-ready files to v1.0
    [optocamzero-transparent_v1.0_bambustudio.3mf, optocamzero_v1.0_bambustudio.3mf]
2026-04-13 added sample photos.md
2026-07-19 Sync firmware to v1.2.0 test image state
    - Calibration: tabbed DISPLAY/COLOR/ADVANCED UI, absolute factory gains
    and contrast shown in sliders, flat neutral gray card, contrast card
    removed, stale-session ghost pattern and brightness-drag flicker fixed
    - Gallery: versioned media URLs so hard-cached thumbnails/GIFs can't go
    stale across reflash or Format Data; GIF frame delays honoured end-to-end
    - Boot: publish the five init stubs (seedrng/syslogd/klogd/sysctl/network)
    the fast-boot image always relied on; add /etc/optocam-version
    - Debug kit: boot-rotating crash forensics capture; transfer-stop log marker
    [optocam_app.cpp, optocam_render.h]
2026-10-18 Firmware cleanup, small-phone gallery toolbar, V.1.2 splash
    - Remove optocam-camera-builtin.fragment: building the camera drivers
    into the kernel breaks unicam's async registration. The lean fragment
    now notes they must stay modules.
    - Drop unused packages from the defconfig (boost program_options, tiff,
    xz) left over from the libcamera-apps attempt.
    - Bump the optocamzero package version to 1.2.0.
    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
2026-10-18 Make the repo reproduce the shipped firmware image
    A fresh Buildroot 2024.02.9 checkout plus these files now builds the
    same image as the release build machine (verified with a from-scratch
    build; boot partition, kernel/busybox configs and /etc + /usr/share
    match).
    - package/libcamera: Raspberry Pi libcamera fork (v0.2.0+rpt20240418)
    with udev disabled, plus a real hash file. Upstream libcamera gives
    photos a blue cast; this override previously lived only on the build
    machine.
    - post-build.sh: create the /boot and /data mount points. They were
    empty overlay directories, which git doesn't keep, so builds from
    the repo couldn't read WiFi settings or mount photo storage.
    - optocamzer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
